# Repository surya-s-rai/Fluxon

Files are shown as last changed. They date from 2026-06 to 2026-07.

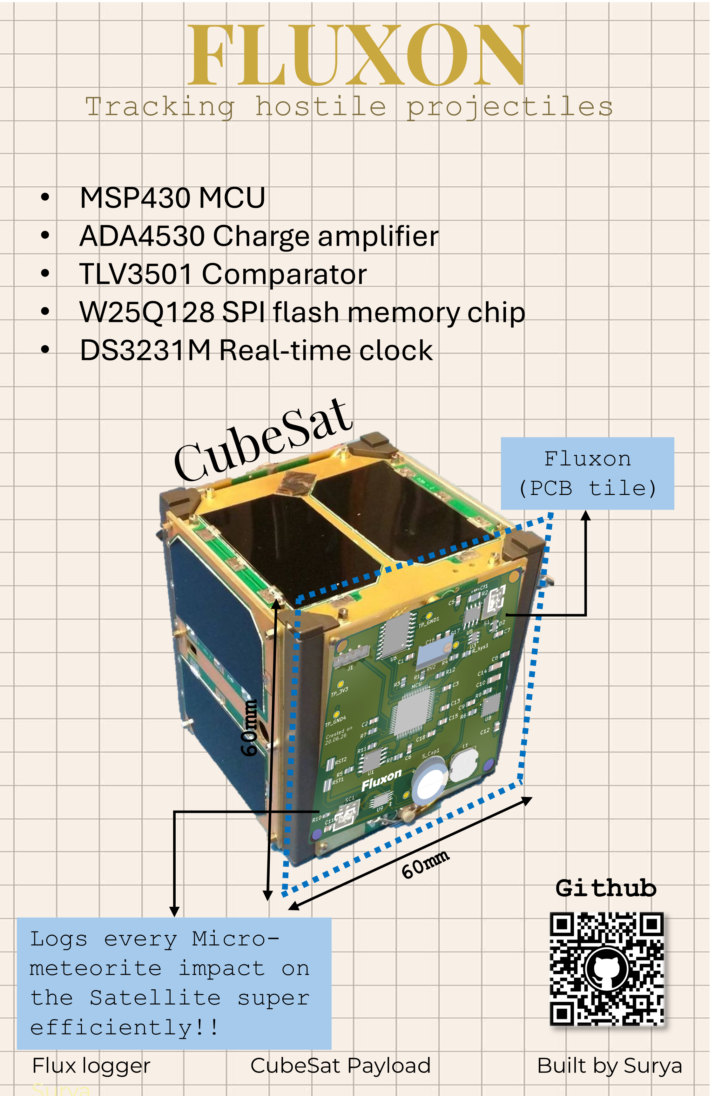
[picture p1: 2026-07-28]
Docs/fallout_Zine.png

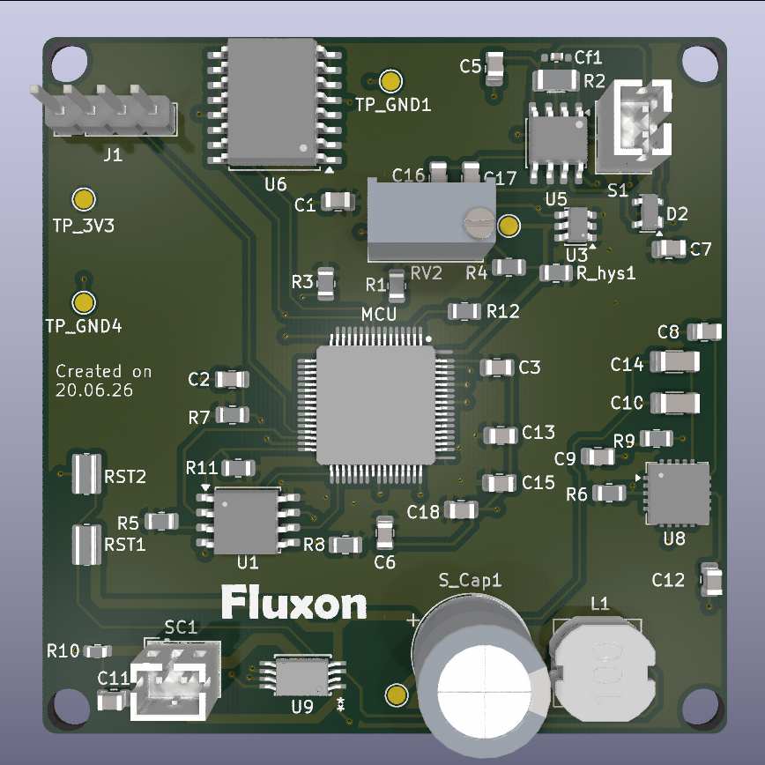
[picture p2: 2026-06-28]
Photos/Front 3d view.png

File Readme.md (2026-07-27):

# Important Information
## Why I did not made a CAD model for my project
Since it is an Iot device designed to be mounted on the CubeSat specifically on it's sidewall, therefore Satellite's outer body made up of Aluminium alloys protects Fluxon from the harsh environment outside. Zine page illustrating Fluxon outside the body is just for the visual representation.

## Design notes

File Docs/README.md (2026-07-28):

# Fluxon
## Project Overview
<p align="center">

fallout_Zine

</p>
<br><br>

__Fluxon__ - A PVDF Sensor based Flux logger that collects collision data, a especailly designed payload for CubeSat\
Collects useful data values once embedded on side walls of the satellite as shown in the Zine page above.
<br><br>


 ## Why I made this
 I made this project for a hardware hackathon called fallout organised by [Hack Club](https://github.com/hackclub), and particularly choosed to make this Iot device as i wanted to make a prototype of something real used in spacecrafts.
 ## Why it is relevant
 * Scientific value: Current flux models like [ORDEM](https://orbitaldebris.jsc.nasa.gov/modeling/ordem.html) and [MASTER](https://conference.sdo.esoc.esa.int/proceedings/sdc3/paper/92/SDC3-paper92.pdf) rely mainly on simulations and ground based radar data. A physical sensor mounted on small satellite misson measures impact data better than any simulation can replicate.
 * Cost effective: Commercial impact detectors used in experiments cost thousands of dollars, whereas Fluxon is an open source, low cost substitute PCB board.
 * Mechanical compatibility with real CubeSats: The 60mm x 60mm form factor matches the standard face panel dimensions of CubeSat.
 * Solar powered: The SPV1040 maximum power point tracker(MPPT) harvests energy form solar cell and charges the supercapacitor which reduces the burden of holding a separate battery into a small scale satellite.
 * Mass-frequency distribution: This statistically relevant distribution is obtained from the measured peak voltage which is proportional to mechanical impulse delivered on the aluminium face panel.
 * Flux density: The DS3231 which is a highly accurate real time clock(RTC) helps us to measure particle flux in units of particles per area per second. Flux density is meaningful beacause it varies with orbital altitude, inclination and the time of year(the earth's debris envionment is not uniform).
 * Impact direction: If we embed Fluxon on each face panel of CubeSat, we can calculate angular distribution of impact using parameters like time difference between sensor pairs, speed of sound in aluminium (6320 m/s) and known sensor geometry.
 ## How it works
 The payload is mainly divided into 4 major chunks-
 ### 1. Sensor Frontend (Impact Detection Hardware)
Converts tiny charge generted by the peizoelectric sensors into a measurable voltage.



 ### 2. Signal Conditioning
 Gives Amplified, noise reduced input for Microcontroller unit. 
 
 

 ### 3. Microcontroller and Firmware
 Processes sensor data and uses specific codes that brigdes the hardware requirements.
 


 ### 4. Data Storage System
 Uses W25Q128JV to store collected events.
 


 ## What's inside this folder
 # PCB Files:
 `* flux logger project.kicad_sch`-contains an illustrative layout of parts and wires used in the project
 
 

 `* flux logger project.kicad_pcb`\-The actual pcb layout with all components placed and routed
 


 # Firmware:
 `* Firmware` folder contains hardware specific C codes for parts to operate
 
 # Other files
 `* Flux logger project.kicad_pro`-links `kicad_sch` and `kicad_pcb` files.
 
 `ChargeAmplifier.kicad_sch`,`TPS_Vin.kicad_sch` and`Thre_comp.Kicad_sch` are sub parts of main schema file i.e. `flux logger project.Kicad_sch` 
 ## Build Guide
 1. Replicate the Repository into your local environment
 
 2. View `flux logger project.kicad_sch`,`flux logger project.kicad_pcb` along with the pcb's 3D View on [Kicad](https://www.kicad.org/)
 
 3. PCB Assembly\
 Solder components in the following order:
 resistors and capacitors,Sensor, ADA4530-1, MSP430, W25Q128JV, Connectors and testpoints

 4. Check High Impedance Areas
 Ensure gaurd ring surrounding Amplifier and Sensor input traces.
 Also, keep sensor input clean and isolated.

 5. Power Supply Check
 Apply 3.3V Supply according to `.kicad_sch` file and verify 3.3V rail across each IC.

 6. Firmware Installation

 #### Required Software
 * Visual Studio Code Editor
 * PlatformIO Extension
 * Texas Instruments MSP430 Toolchain

 7. Build and Upload Firware

 * Open Firmware folder and run `pio run` on CLI

 * Use upload Button on PlatformIO in order to upload the programme

## BOM
| Value | Reference | Footprint | Qty | Unit Price | Total Price | URL |
| :--- | :--- | :--- | :--- | :--- | :--- | :--- |
| 100nf | C1,C2,C3,C5,C6,C7,C13,C15,C16 | Capacitor_SMD:C_0805_2012Metric | 9 | $0.01 | $0.11 | https://projectpoint.in/index.php?route=product/product&product_id=636107122 |
| 1uf | C17,C12 | Capacitor_SMD:C_0805_2012Metric | 2 | $0.02 | $0.05 | https://robu.in/product/1uf-1000nf-50v-capacitor-0805-smd-package-pack-of-10/ |
| 10uF | C9,C11,C8,C18 | Capacitor_SMD:C_0805_2012Metric | 4 | $0.04 | $0.16 | https://robu.in/product/grm21bb31c106me15l-murata-electronics-16v-10uf-%C2%B120-0805-multilayer-ceramic-capacitors-mlcc-smd-smt-rohs/ |
| 22uF | C10,C14 | Capacitor_SMD:C_1206_3216Metric | 2 | $0.01 | $0.02 | https://robu.in/product/cs3216x5r226m6r3nri-samwha-6-3v-22uf-x5r-%C2%B120-1206-multilayer-ceramic-capacitors-mlcc-smd-smt-rohs/ |
| 10pf | Cf1 | Resistor_SMD:R_0603_1608Metric | 1 | $0.01 | $0.01 | https://robu.in/product/10pf-0603-surface-mount-multilayer-ceramic-capacitor-pack-of-50/ |
| 100mf | S_Cap1 | Capacitor_THT:CP_Radial_D10.0mm_P5.00mm | 1 | $1.18 | $1.18 | https://robu.in/product/0-1f-5-5v-dip-super-capacitor/ |
| Conn_01x04 | J1 | Connector_PinHeader_2.54mm:PinHeader_1x02_P2.54mm_Vertical | 2 | $0.02 | $0.04 | https://ifuturetech.org/product/xh2-54-2p-curved-needle-connector-holder-2-54mm-white/ |
| 22uH | L2 | Inductor_SMD:L_7.3x7.3_H4.5 | 1 | $0.10 | $0.10 | https://robu.in/product/68mm-22%C2%B5h-dip-power-inductor-pack-of-5/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 |
| 10K | RV2 | Potentiometer_THT:Potentiometer_Bourns_3296W_Vertical | 1 | $0.17 | $0.17 | https://projectpoint.in/index.php?route=product/product&product_id=1500453261 |
| 4.7K | R1,R3 | Resistor_SMD:R_0805_2012Metric | 2 | $0.01 | $0.01 | https://robu.in/product/yageo-4-7k-ohm-1-4w-0805-surface-mount-resistor-pack-of-50/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 |
| 100M | R2 | Resistor_SMD:R_1206_3216Metric | 1 | $1.01 | $1.01 | https://srkelectronics.in/product/1-mega-ohm-1206-smd-resistor-cfr-pack-of-100/ |
| 470K | R10 | Resistor_SMD:R_0603_1608Metric | 1 | $0.10 | $0.10 | https://quartzcomponents.com/products/470k-ohm-0603-package-1-10w-smd-resistor-5-tolerance-pack-of-20-pieces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 |
| 10K | R5,R8,R4,R11 | Resistor_SMD:R_1206_3216Metric | 4 | $0.01 | $0.03 | https://robu.in/product/10k-ohm-1-4w-1206-surface-mount-chip-resistor-pack-of-100/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 |
| 13.3K | R6 | Resistor_SMD:R_1206_3216Metric | 1 | $0.02 | $0.02 | https://projectpoint.in/index.php?route=product/product&product_id=499506064082 |
| 47k | R7 | Resistor_SMD:R_1206_3216Metric | 1 | $0.02 | $0.02 | https://projectpoint.in/index.php?route=product/product&product_id=501263610758 |
| 9.1K | R9 | Resistor_SMD:R_1206_3216Metric | 1 | $0.02 | $0.02 | https://projectpoint.in/index.php?route=product/product&product_id=502522332251 |
| 220K | RST1 | Resistor_SMD:R_1206_3216Metric | 1 | $0.02 | $0.02 | https://projectpoint.in/index.php?route=product/product&product_id=501903421507 |
| 100K | RST2 | Resistor_SMD:R_1206_3216Metric | 1 | $0.01 | $0.01 | https://robu.in/product/100k-ohm-1-4w-1206-surface-mount-chip-resistor-pack-of-100/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 |
| 1M | R_hys1 | Resistor_SMD:R_0603_1608Metric | 1 | $0.11 | $0.11 | https://quartzcomponents.com/products/yageo-1m-ohm-0603-package-1-10w-smd-resistor-1-tolerance-pack-of-20-pieces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 |
| 1K | R12 | Resistor_SMD:R_1206_3216Metric | 1 | $0.01 | $0.01 | https://robu.in/product/1k-ohm-1-4w-1206-surface-mount-chip-resistor-pack-of-100/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 |
| PDVF Sensor | S1 | Connector_JST:JST_PH_B2B-PH-K_1x02_P2.00mm_Vertical | 1 | $0.50 | $0.50 | https://www.flyrobo.in/10cm-2pin-jst-male-female-plug-connector-plug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 |
| Solar_Cell | SC2 | Connector_JST:JST_PH_B2B-PH-K_1x02_P2.00mm_Vertical | 1 | $0.50 | $0.50 | https://www.flyrobo.in/10cm-2pin-jst-male-female-plug-connector-plug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 |
| PRTR5V0U2X | D2 | Package_TO_SOT_SMD:SOT-143 | 1 | $1.00 | $1.00 | https://www.digikey.in/en/products/detail/microchip-technology/MIC5203-5.0YM4-TR/771725 |
| W25Q128JVS | U1 | Package_SO:SOIC-8_5.3x5.3mm_P1.27mm | 1 | $2.65 | $2.65 | https://evelta.com/serial-nor-flash-memory-128mbit-8pin-soic/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 |
| TLV3501AIDBV | U3 | Package_TO_SOT_SMD:SOT-23-6 | 1 | $4.00 | $4.00 | https://www.mouser.in/ProductDetail/Texas-Instruments/TLV3501AIDR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 |
| MSP430FR5994IPMR.B | U4 | MCU:MSP430FR footprint | 1 | $11.06 | $11.06 | https://www.mouser.in/ProductDetail/Texas-Instruments/MSP430FR5994IPMR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 |
| ADA4530-1 | U5 | Package_SO:SOIC-8_3.9x4.9mm_P1.27mm | 1 | $42.61 | $42.61 | https://www.mouser.in/ProductDetail/Analog-Devices/ADA4530-1ARZ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 |
| DS3231M | U6 | Package_SO:SOIC-16W_7.5x10.3mm_P1.27mm | 1 | $2.60 | $2.60 | https://robu.in/product/ds3231-ic-real-time-clock-integrated-rtc-tcxo-crystal/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 |
| TPS7A4701xRGW | U8 | Package_DFN_QFN:Texas_RGW0020A_VQFN-20-1EP_5x5mm_P0.65mm_EP3.15x3.15mm_ThermalVias | 1 | $6.44 | $6.44 | https://www.lioncircuits.com/parts/TPS7A4701RGWR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 |
| SPV1040TTR | U9 | Package_DFN_QFN:SOIC_1040T_STM | 1 | $4.07 | $4.07 | https://www.digikey.in/en/products/detail/stmicroelectronics/SPV1040TTR/2672694 |
| TesPoint | TP_3v3, TP_GND1,TP_GND4, TP_SCAP1,TP_COMP1 | TestPoint:TestPoint_Pad_D1.5mm | 5 | $0.19 | $0.93 | https://in.element14.com/keystone/5000/test-point-pcb-color-coded/dp/2250281 |
|  |  |  |  | TOTAL= | $79.56 |  |

  ## Credit
  I thank this project to-\
  [Kicad](https://www.kicad.org/)\
  [HackClub Fallout](https://fallout.hackclub.com)\
  my beloved parents and friends...

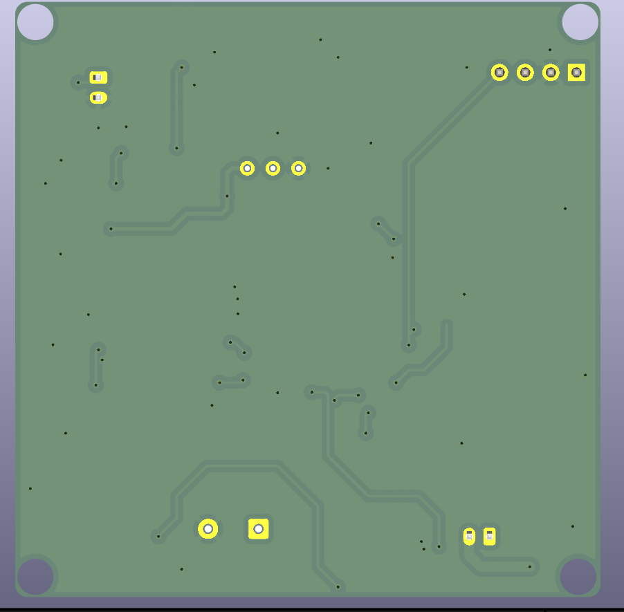
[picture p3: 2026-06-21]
Photos/3D View Back.png

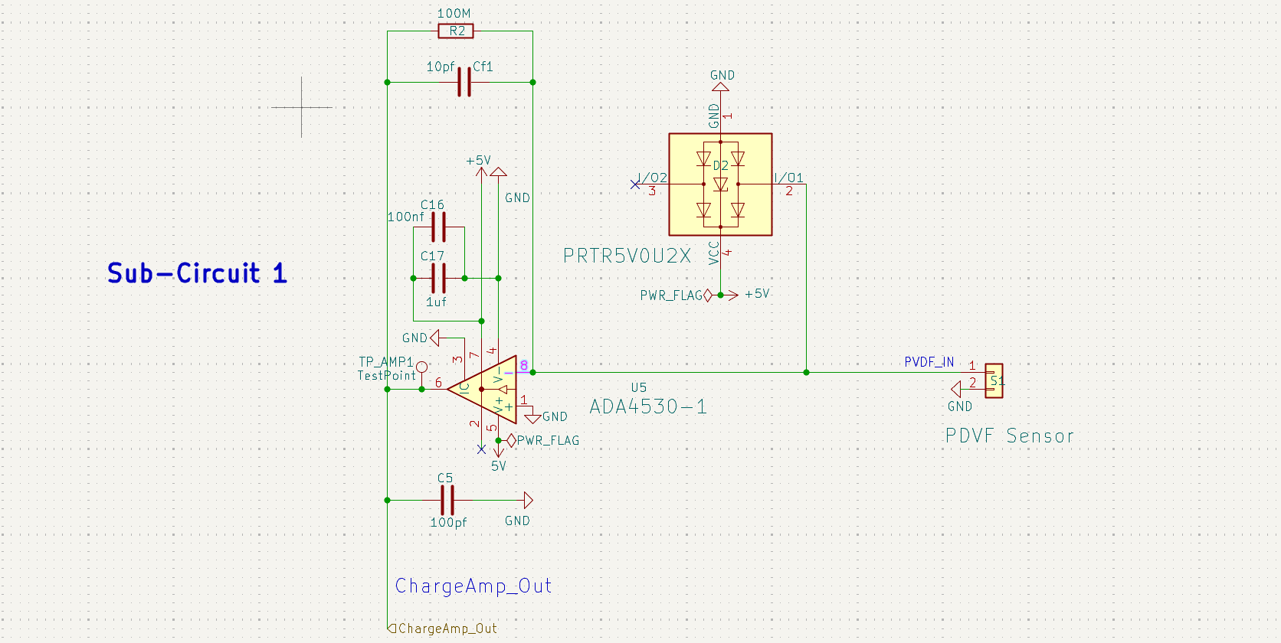
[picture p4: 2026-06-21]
Photos/Sensor and Amp Schema.png

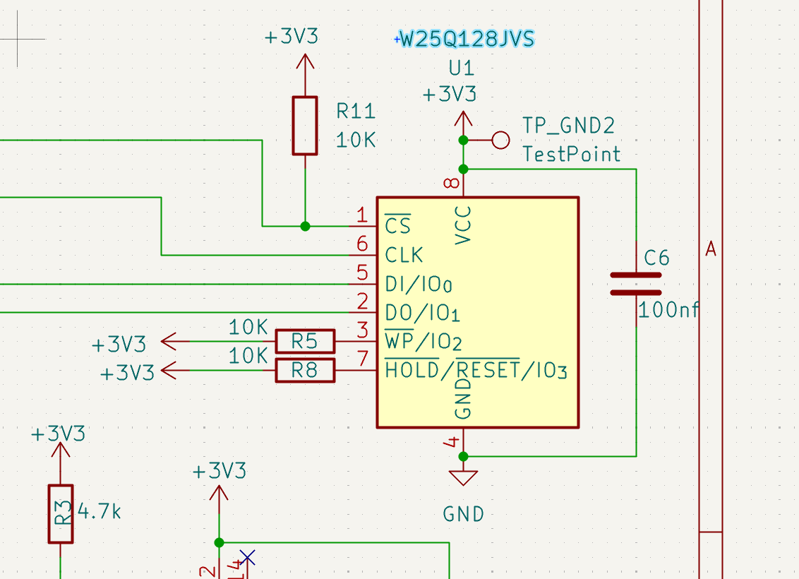
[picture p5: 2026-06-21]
Photos/RTC Schema.png

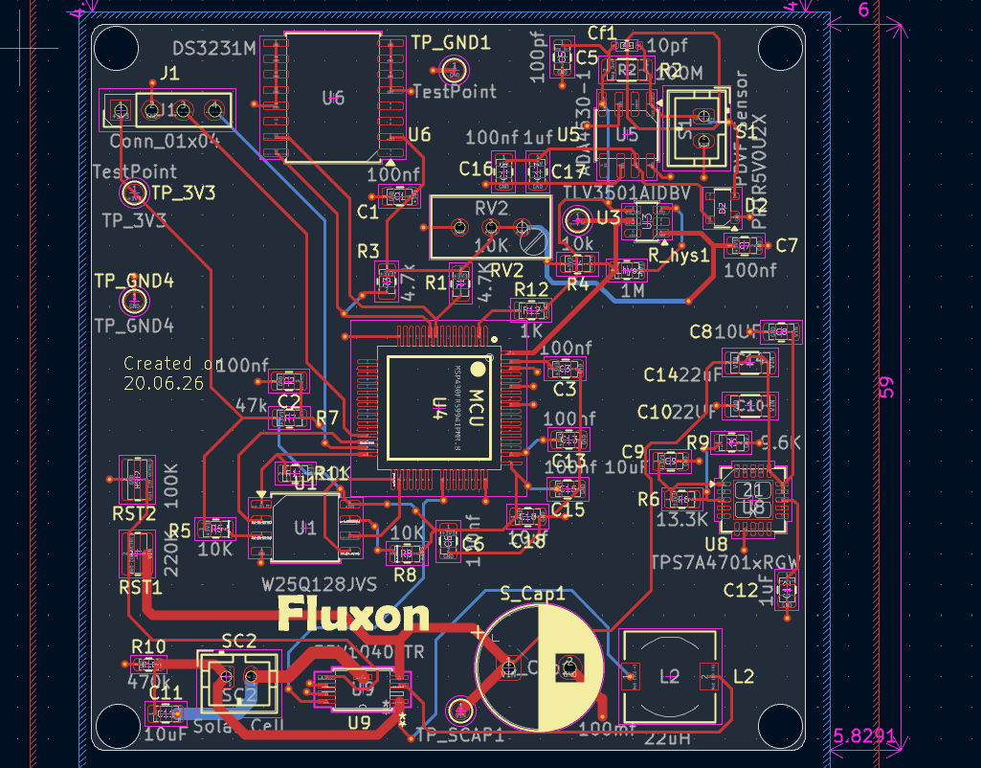
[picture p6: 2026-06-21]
Photos/PCB editor Front view.png

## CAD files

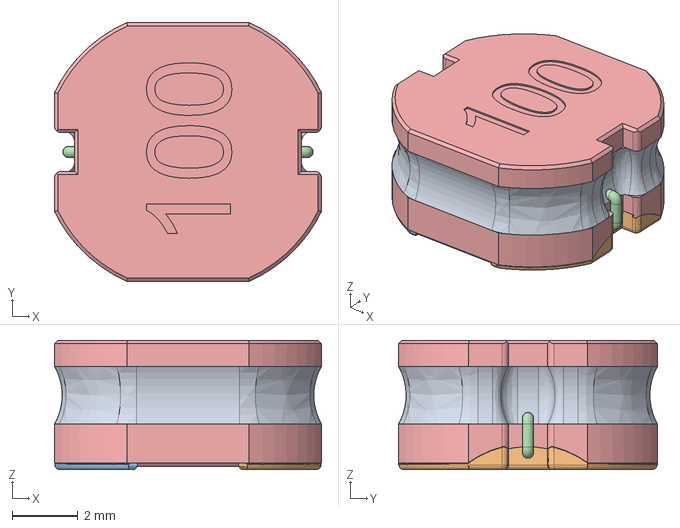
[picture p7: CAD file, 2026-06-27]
3rd party Assets/Inductor 3d model only/SRN8040-220M.stp
8.15 x 7.90 x 3.95 mm

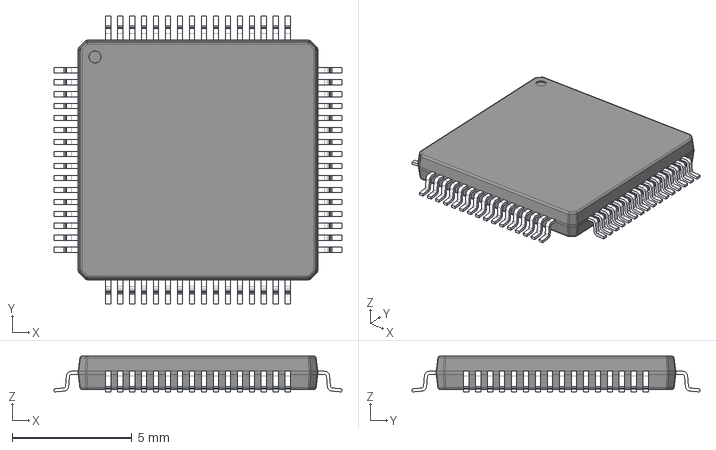
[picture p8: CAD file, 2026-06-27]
3rd party Assets/MCU/MCU 3d model/MSP430FR5994IPMR.stp
12.0 x 12.0 x 1.50 mm
BODY-QFP
LEAD-QFP x 64

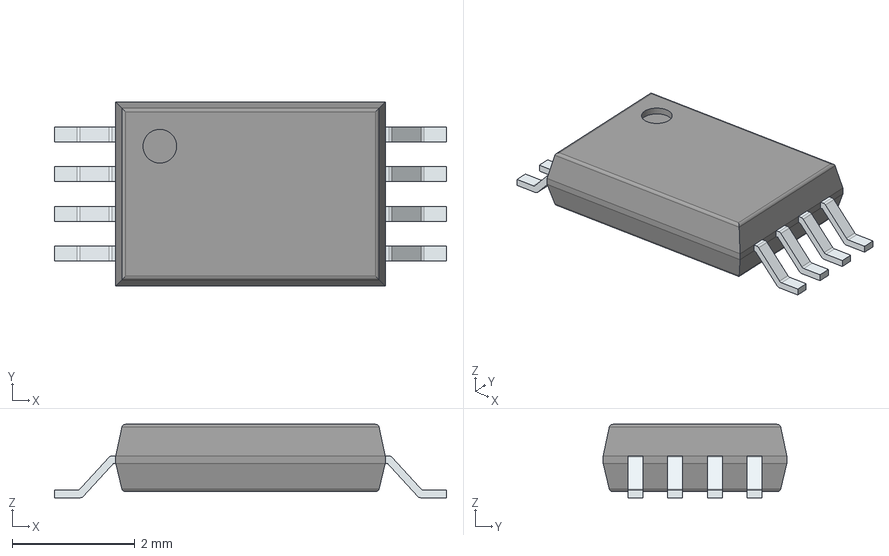
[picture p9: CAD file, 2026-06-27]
3rd party Assets/SPV1040TTR/SPV1040TTR 3d model/SPV1040TTR.stp
6.40 x 3.00 x 1.20 mm
PinsArrayLR

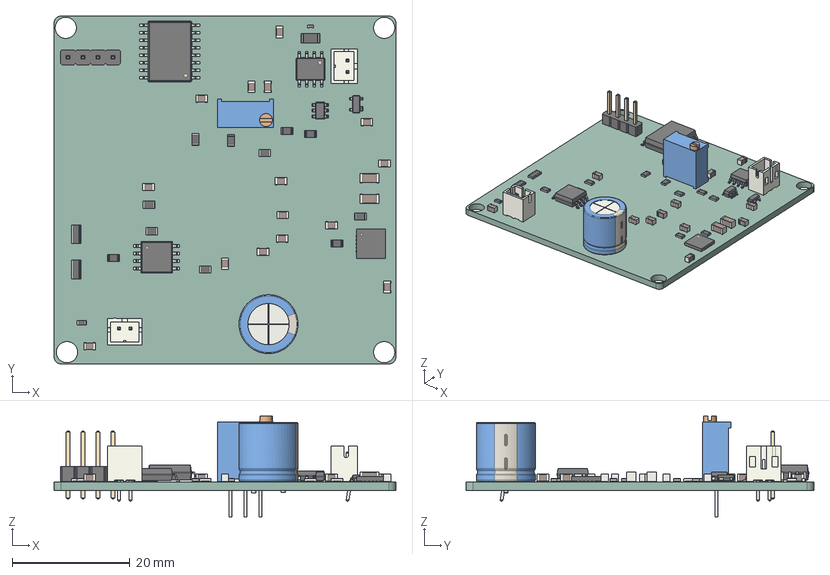
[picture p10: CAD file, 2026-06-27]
CAD/flux logger project.step
58.0 x 59.0 x 17.1 mm
JST_B2B_PH_K x 2
CP_Radial_D100mm_P500mm
C_0805_2012Metric x 15
SOIC-8_3.9x4.9mm_P1.27mm
R_0805_2012Metric x 11
R_0612_1632Metric x 2
C_1206_3216Metric x 2
Potentiometer_Bourns_3296W_Vertical
SOT-23-6
PinHeader_1x04_P254mm_Vertical
C_0402_1005Metric
SOIC-16W_7.5x10.3mm_P1.27mm
R_1206_3216Metric
SOIC-8_5.3x5.3mm_P1.27mm
R_0603_1608Metric
SOT-143
Texas_RGW0020A_VQFN-20-1EP_5x5mm_P0.65mm_EP3.15x3.15mm
flux logger project_PCB

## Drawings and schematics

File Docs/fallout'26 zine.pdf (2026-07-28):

# FLUXON 60mm

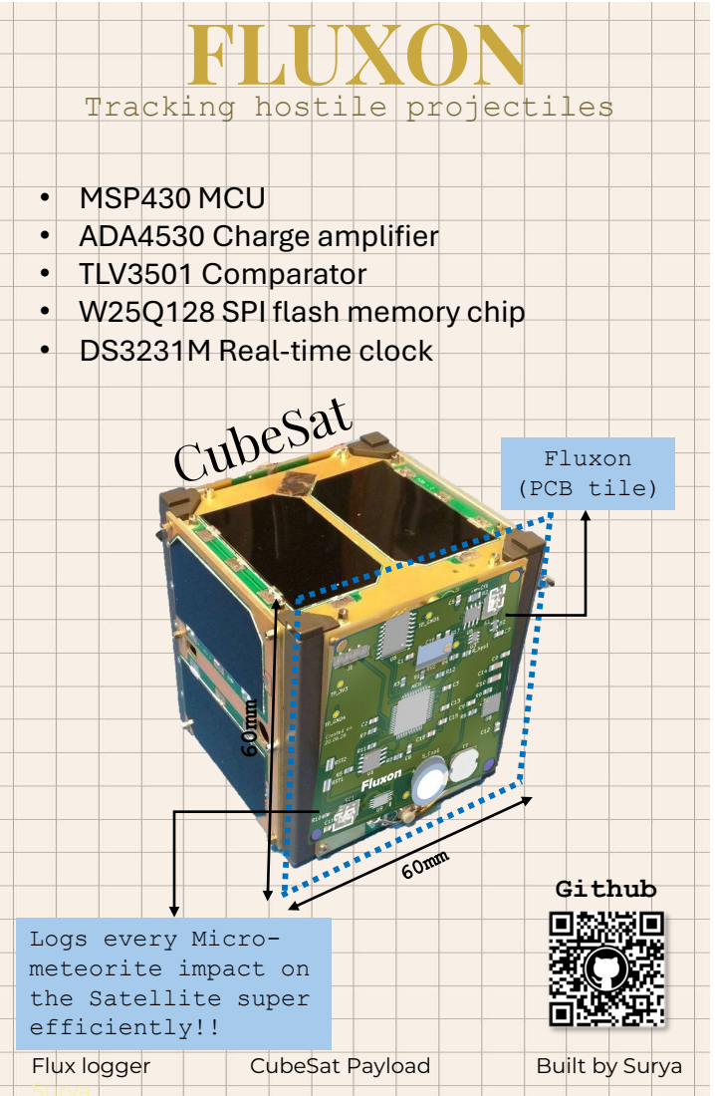
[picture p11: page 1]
Github; Flux logger; CubeSat Payload; Built by Surya; Fluxon; (PCB tile)

Tracking hostile projectiles

• MSP430 MCU
• ADA4530 Charge amplifier
• TLV3501 Comparator
• W25Q128 SPI flash memory chip
• DS3231M Real-time clock

Logs every Micro-
meteorite impact on
the Satellite super
efficiently!!
Surya

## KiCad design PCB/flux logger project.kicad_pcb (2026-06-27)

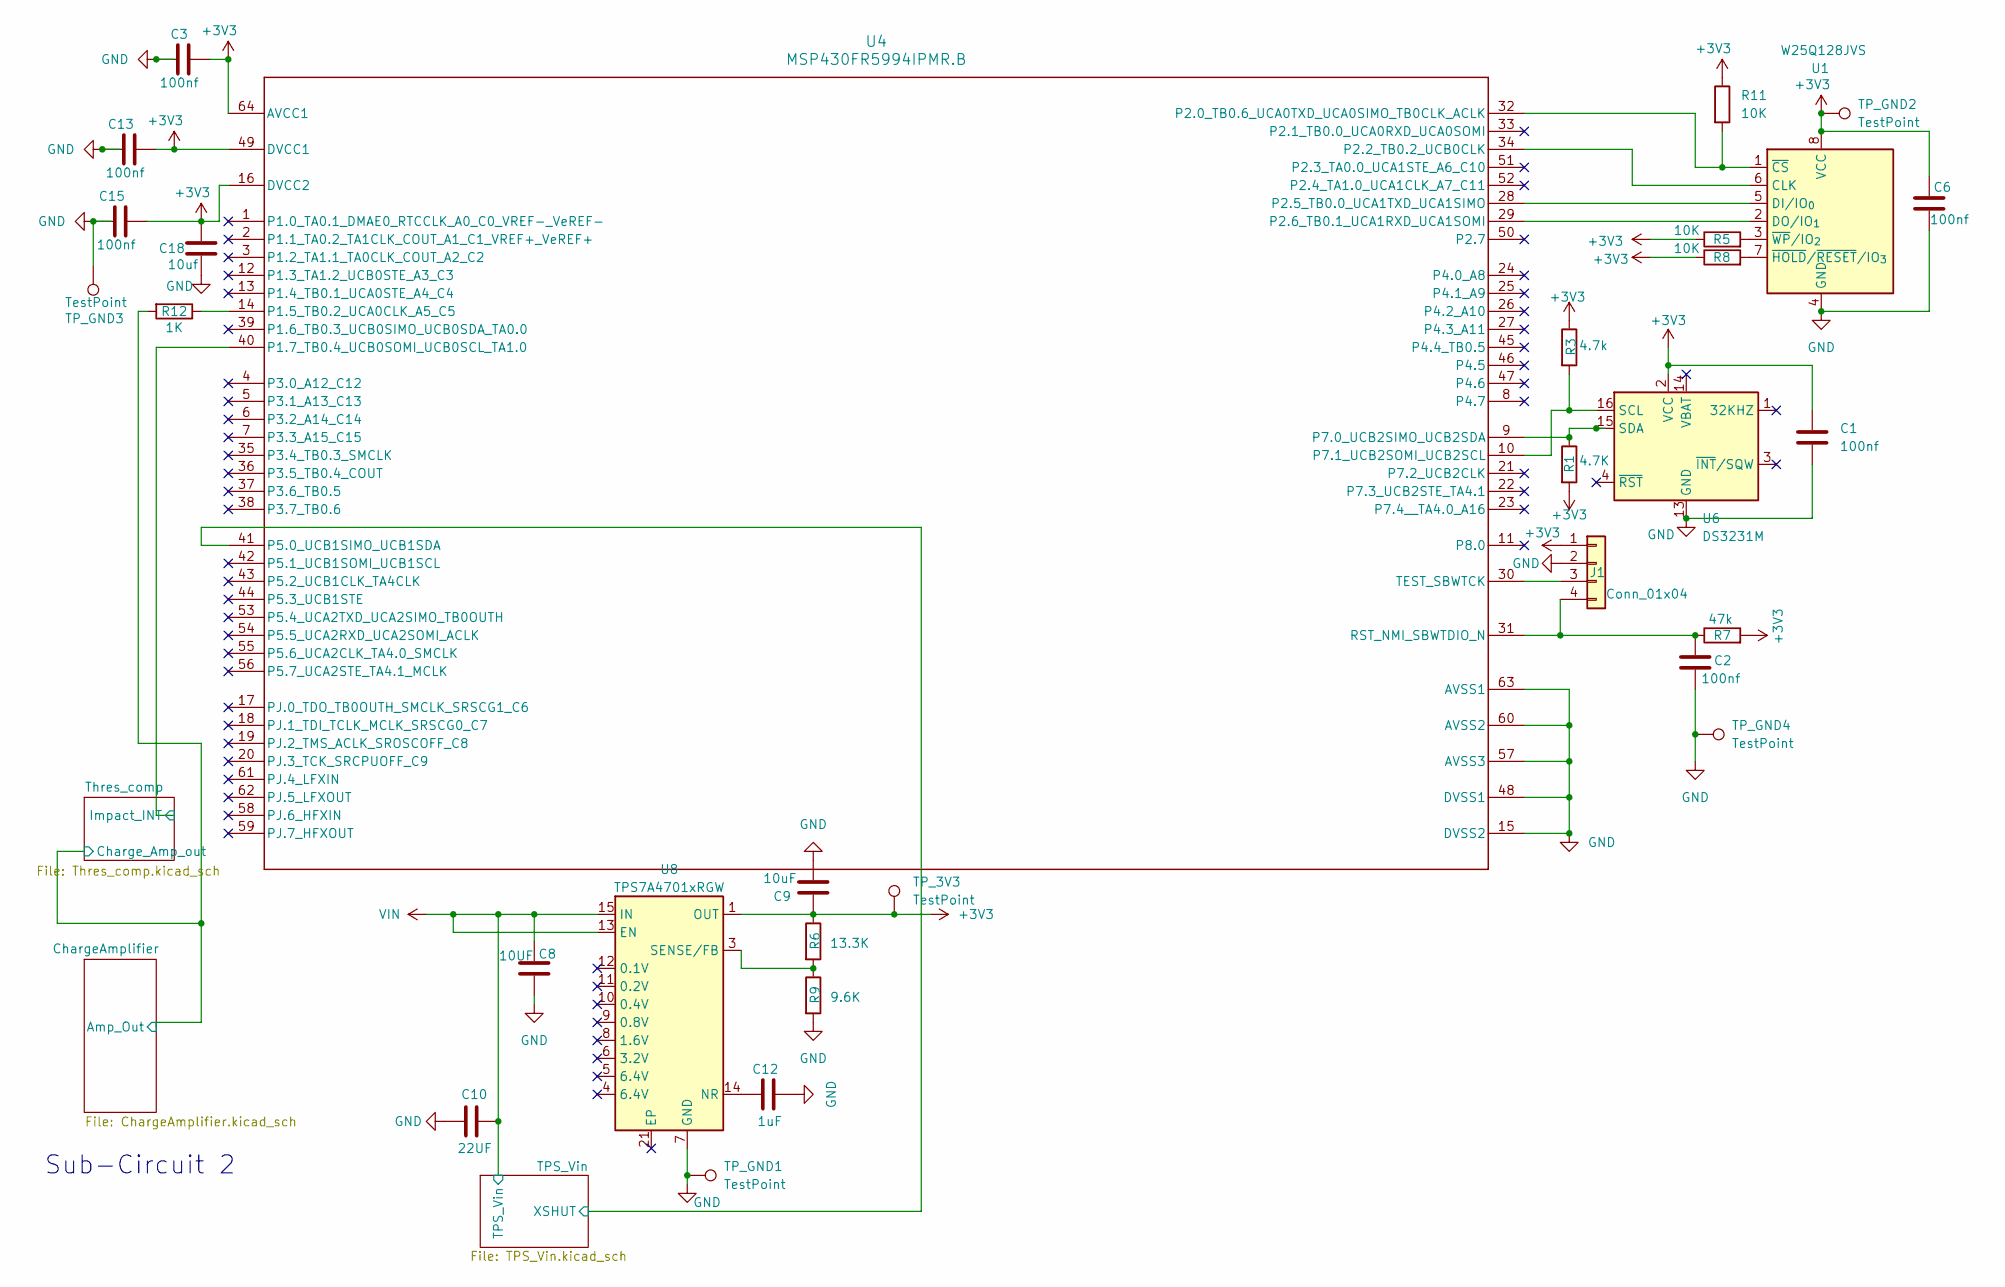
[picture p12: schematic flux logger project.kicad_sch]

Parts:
C1, C2, C3, C6, C13, C15: 100nf; C_0805_2012Metric
C8: 10UF; C_0805_2012Metric
C9: 10uF; C_0805_2012Metric
C10: 22UF; C_1206_3216Metric
C12: 1uF; C_0805_2012Metric
C18: 10uf; C_0805_2012Metric
J1: Conn_01x04; PinHeader_1x04_P2.54mm_Vertical
R1: 4.7K; R_0805_2012Metric
R3: 4.7k; R_0805_2012Metric
R5, R8, R11: 10K; R_0805_2012Metric
R6: 13.3K; R_0805_2012Metric
R7: 47k; R_0805_2012Metric
R9: 9.6K; R_0805_2012Metric
R12: 1K; R_0805_2012Metric
TP_3V3: TestPoint; TestPoint_Pad_D1.5mm
TP_GND1, TP_GND2, TP_GND3, TP_GND4: TestPoint; TestPoint_Pad_D1.5mm
U1: W25Q128JVS; SOIC-8_5.3x5.3mm_P1.27mm
U4: MSP430FR5994IPMR.B; MSP430FR footprint
U6: DS3231M; SOIC-16W_7.5x10.3mm_P1.27mm
U8: TPS7A4701xRGW; Texas_RGW0020A_VQFN-20-1EP_5x5mm_P0.65mm_EP3.15x3.15mm_Ther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

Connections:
+3V3: C1.1, C3.2, C6.1, C9.1, C13.2, C15.2, C18.1, J1.1, R1.2, R3.1, R5.1, R6.1, R7.2, R8.1, R11.1, TP_3V3.1 (1_1), TP_GND2.1, U1.8 (VCC), U4.16 (DVCC2), U4.49 (DVCC1), U4.64 (AVCC1), U6.2 (VCC), U8.1 (OUT); also elsewhere on the board
/ChargeAmplifier/Amp_Out: R12.2; also elsewhere on the board
/TPS_Vin/XSHUT: U4.41 (P5.0_UCB1SIMO_UCB1SDA); also elsewhere on the board
/Thres_comp/Impact_INT: U4.40 (P1.7_TB0.4_UCB0SOMI_UCB0SCL_TA1.0); also elsewhere on the board
GND: C1.2, C2.2, C3.1, C6.2, C8.2, C9.2, C10.2, C12.2, C13.1, C15.1, C18.2, J1.2, R9.2, TP_GND1.1 (1_1), TP_GND3.1, TP_GND4.1 (1_1), U1.4 (GND), U4.15 (DVSS2), U4.48 (DVSS1), U4.57 (AVSS3), U4.60 (AVSS2), U4.63 (AVSS1), U6.5 (GND), U6.6 (GND), U6.7 (GND), U6.8 (GND), U6.9 (GND), U6.10 (GND), U6.11 (GND), U6.12 (GND), U6.13 (GND), U8.7 (GND); also elsewhere on the board
unnamed: J1.3, U4.30 (TEST_SBWTCK)
unnamed: C2.1, J1.4, R7.1, U4.31 (RST_NMI_SBWTDIO_N)
unnamed: U1.6 (CLK), U4.34 (P2.2_TB0.2_UCB0CLK)
unnamed: U1.5 (DI/IO_{0}), U4.28 (P2.5_TB0.0_UCA1TXD_UCA1SIMO)
unnamed: U1.2 (DO/IO_{1}), U4.29 (P2.6_TB0.1_UCA1RXD_UCA1SOMI)
unnamed: R11.2, U1.1 (~CS), U4.32 (P2.0_TB0.6_UCA0TXD_UCA0SIMO_TB0CLK_ACLK)
unnamed: R8.2, U1.7 (~HOLD/~RESET/IO_{3})
unnamed: R5.2, U1.3 (~WP/IO_{2})
unnamed: R12.1, U4.14 (P1.5_TB0.2_UCA0CLK_A5_C5)
unnamed: R1.1, U4.9 (P7.0_UCB2SIMO_UCB2SDA), U6.15 (SDA)
unnamed: R3.2, U4.10 (P7.1_UCB2SOMI_UCB2SCL), U6.16 (SCL)
unnamed: C12.1, U8.14 (NR)
unnamed: R6.2, R9.1, U8.3 (SENSE/FB)
VIN: C8.1, C10.1, U8.13 (EN), U8.15 (IN), U8.16 (IN); also elsewhere on the board

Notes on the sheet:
Sub-Circuit 2

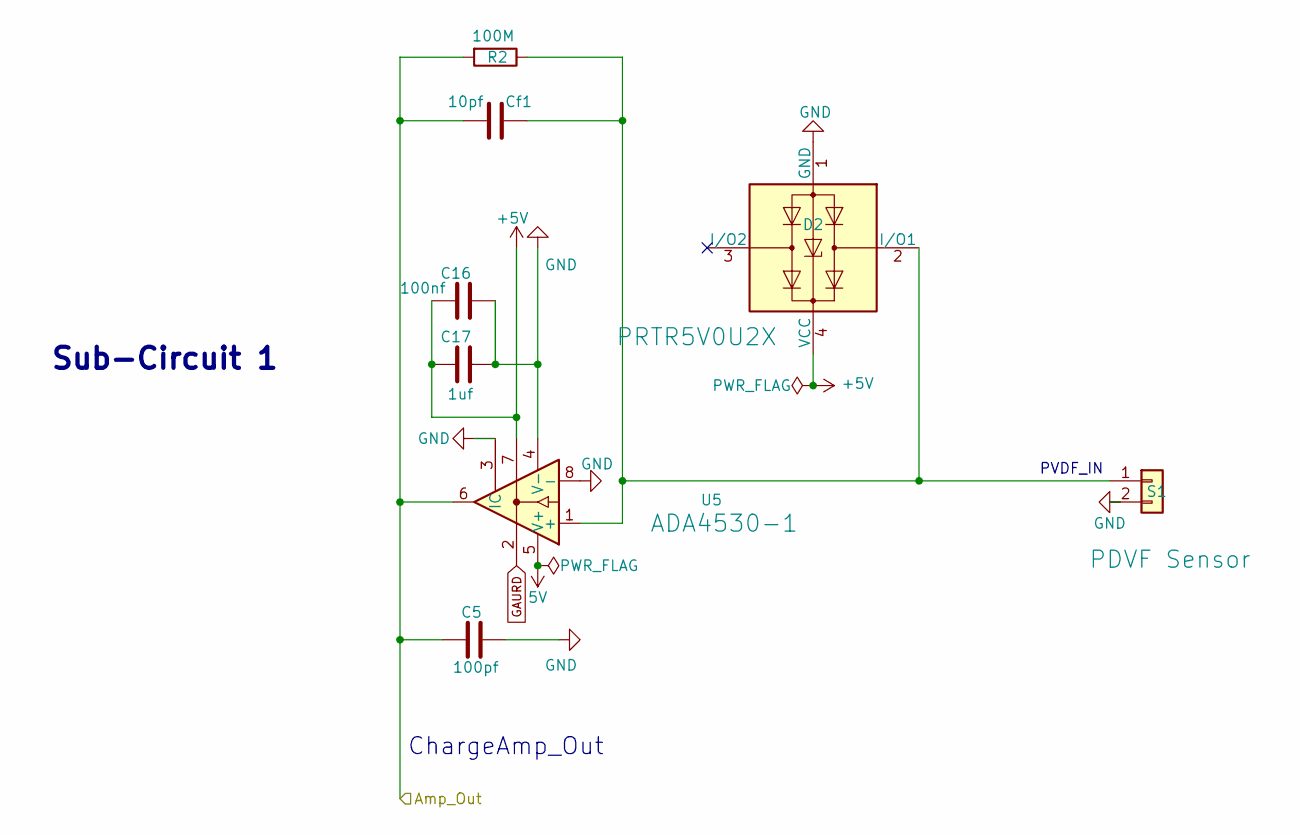
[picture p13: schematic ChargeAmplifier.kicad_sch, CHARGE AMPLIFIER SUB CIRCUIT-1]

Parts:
C5: 100pf; C_0805_2012Metric
C16: 100nf; C_0805_2012Metric
C17: 1uf; C_0805_2012Metric
Cf1: 10pf; C_0402_1005Metric
D2: PRTR5V0U2X; SOT-143
R2: 100M; R_1206_3216Metric
S1: PDVF Sensor; JST_PH_B2B-PH-K_1x02_P2.00mm_Vertical
U5: ADA4530-1; SOIC-8_3.9x4.9mm_P1.27mm

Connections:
5V: U5.5 (V+)
+5V: C16.1, C17.1, D2.4 (VCC), U5.7
/ChargeAmplifier/Amp_Out: C5.1, Cf1.2, R2.2, U5.6; also elsewhere on the board
GAURD: U5.2
GND: C5.2, C16.2, C17.2, D2.1 (GND), S1.2, U5.3 (IC), U5.4 (V-), U5.8 (-); also elsewhere on the board
unnamed: Cf1.1, D2.2 (I/O1), R2.1, S1.1, U5.1 (+)

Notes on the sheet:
ChargeAmp_Out
PVDF_IN
Sub-Circuit 1

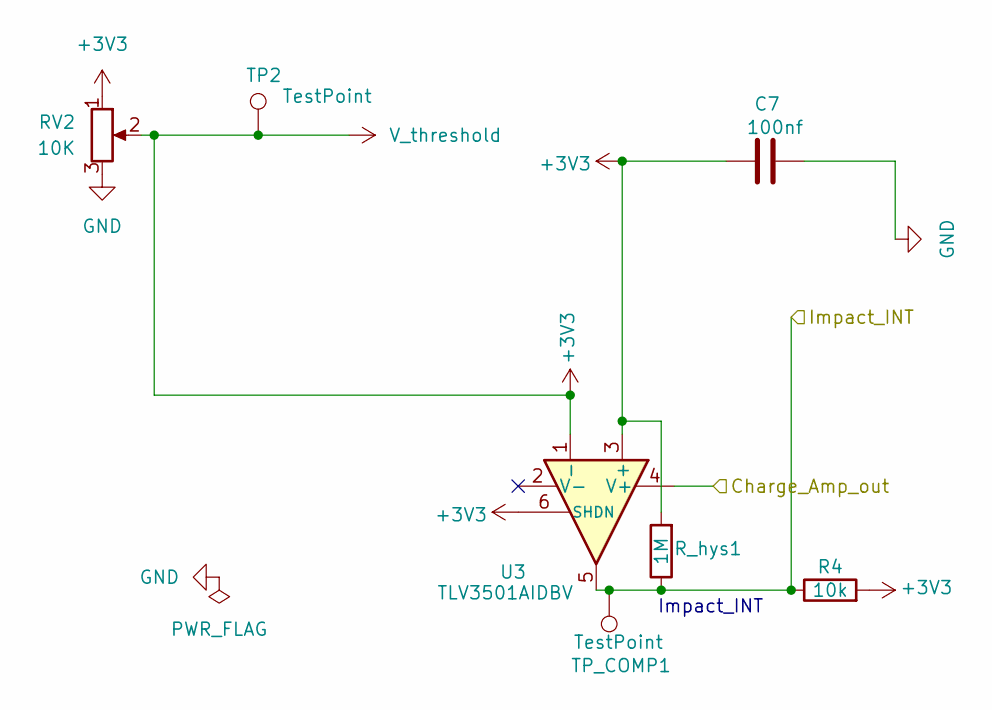
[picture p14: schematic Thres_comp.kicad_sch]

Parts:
C7: 100nf; C_0805_2012Metric
R4: 10k; R_0805_2012Metric
RV2: 10K; Potentiometer_Bourns_3296W_Vertical
R_hys1: 1M; R_0805_2012Metric
TP2: TestPoint; TestPoint_Pad_D1.5mm
TP_COMP1: TestPoint; TestPoint_Pad_D1.5mm
U3: TLV3501AIDBV; SOT-23-6

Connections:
+3V3: C7.1, R4.2, RV2.1, RV2.2, R_hys1.2, TP2.1, U3.1 (-), U3.3 (+), U3.6 (SHDN); also elsewhere on the board
/ChargeAmplifier/Amp_Out: U3.4 (V+); also elsewhere on the board
/Thres_comp/Impact_INT: R4.1, R_hys1.1, TP_COMP1.1 (1_1), U3.5; also elsewhere on the board
GND: C7.2, RV2.3; also elsewhere on the board

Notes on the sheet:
Impact_INT

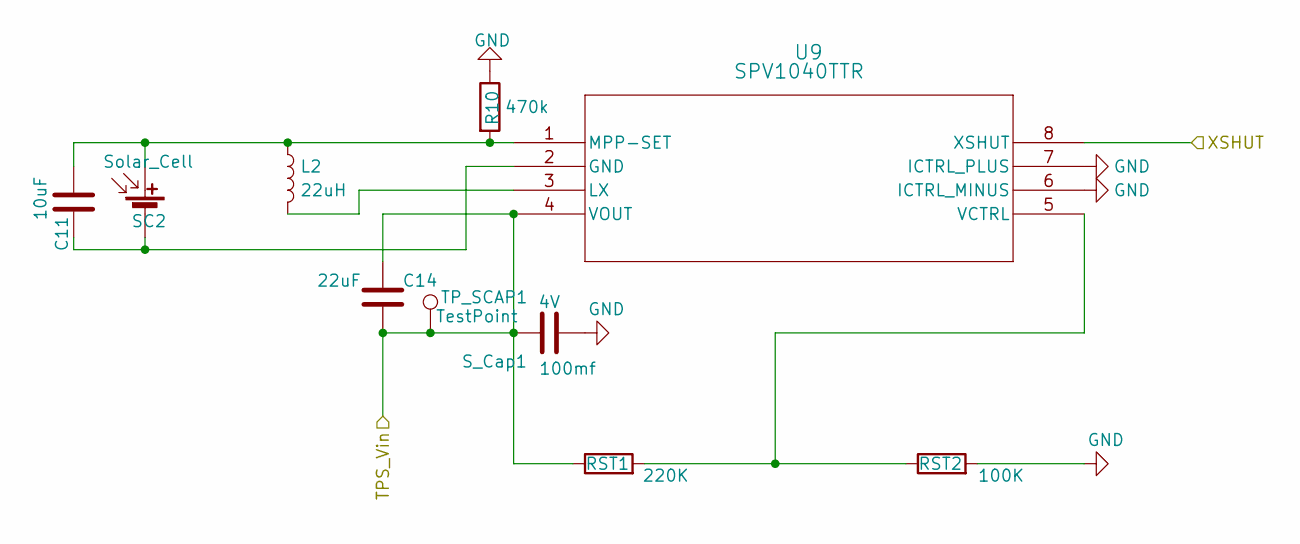
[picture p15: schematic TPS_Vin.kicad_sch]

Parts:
C11: 10uF; C_0805_2012Metric
C14: 22uF; C_1206_3216Metric
L2: 22uH; L_7.3x7.3_H4.5
R10: 470k; R_0603_1608Metric
RST1: 220K; R_0612_1632Metric
RST2: 100K; R_0612_1632Metric
SC2: Solar_Cell; JST_PH_B2B-PH-K_1x02_P2.00mm_Vertical
S_Cap1: 100mf; CP_Radial_D10.0mm_P5.00mm; Voltage 4V
TP_SCAP1: TestPoint; TestPoint_Pad_D1.5mm
U9: SPV1040TTR; SOIC_1040T_STM

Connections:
/TPS_Vin/XSHUT: U9.8 (XSHUT); also elsewhere on the board
GND: R10.1, RST2.2, S_Cap1.2, U9.6 (ICTRL_MINUS), U9.7 (ICTRL_PLUS); also elsewhere on the board
unnamed 11: C11.1, L2.1, R10.2, SC2.1 (+), U9.1 (MPP-SET); also elsewhere on the board
unnamed 12: C11.2, SC2.2 (-), U9.2 (GND); also elsewhere on the board
unnamed 24: L2.2, U9.3 (LX); also elsewhere on the board
unnamed: RST1.2, RST2.1, U9.5 (VCTRL)
VIN: C14.1, C14.2, RST1.1, S_Cap1.1, TP_SCAP1.1 (1_1), U9.4 (VOUT); also elsewhere on the board

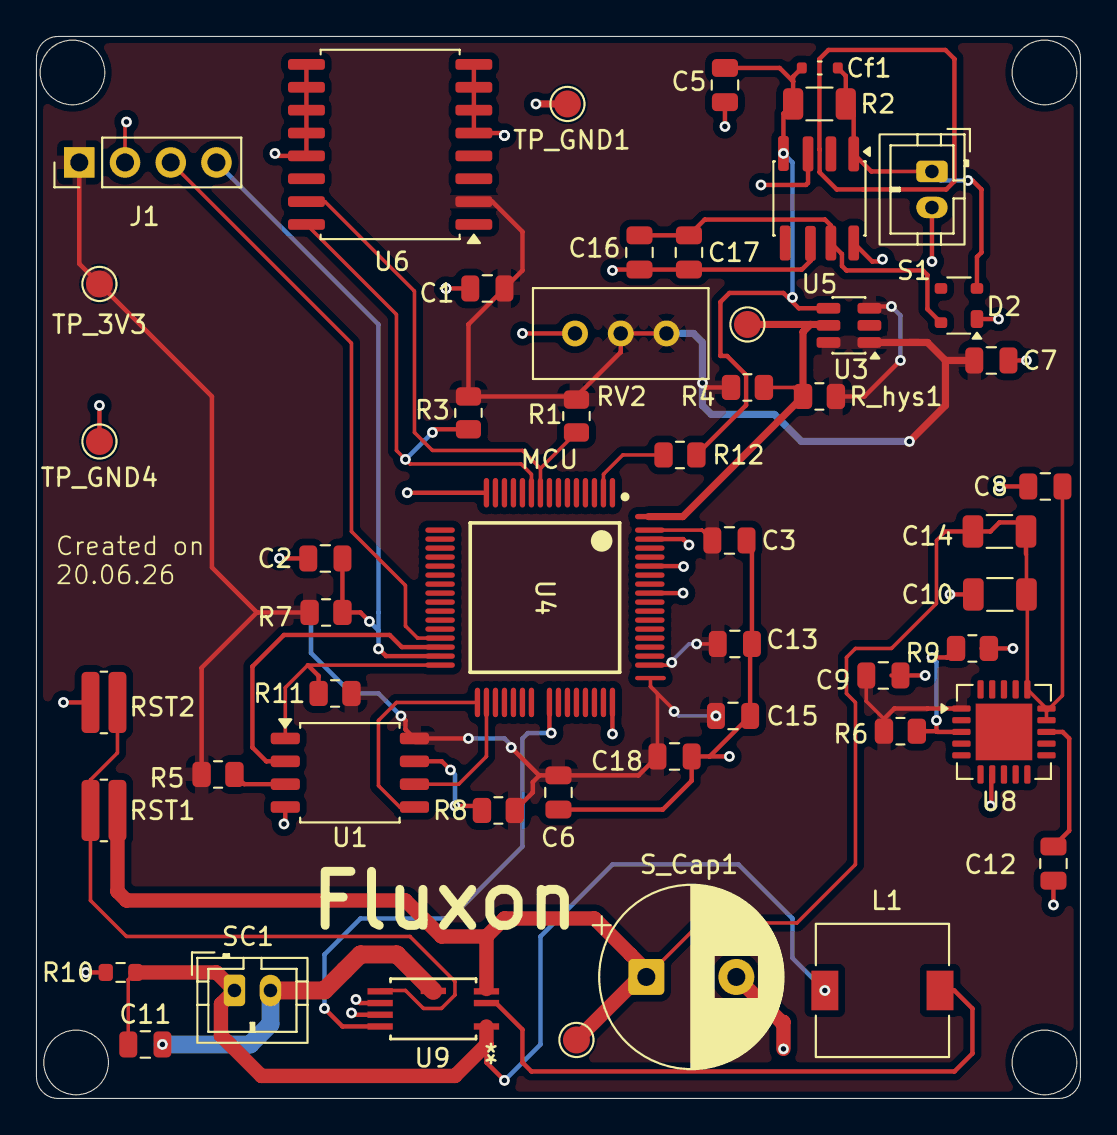
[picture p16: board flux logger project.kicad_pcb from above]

Board: 2 copper layers, 58.0 x 59.0 mm, 52 parts (0 on the bottom side), 25 nets.

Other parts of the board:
L1: 22uH; L_7.3x7.3_H4.5
SC1: Solar_Cell; JST_PH_B2B-PH-K_1x02_P2.00mm_Vertical

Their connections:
unnamed 11: L1.1, SC1.1 (+); also elsewhere on the board
unnamed 12: SC1.2 (-); also elsewhere on the board
unnamed 24: L1.2; also elsewhere on the board

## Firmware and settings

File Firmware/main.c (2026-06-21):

#include <msp430.h>
#include "impact_detector.h"
#include "adc_monitor.h"
#include "logger.h"
int main(void)
{
    WDTCTL = WDTPW | WDTHOLD;   // Stop watchdog timer
    Impact_Init();
    ADC_Init();
    Flash_Init();
    _enable_interrupt();
    while(1){
        if(impactFlag){
            impactFlag=0;
            Logger_SaveEvent();
        }
        __bis_SR_register(LPM3_bits + GIE);
    }
}

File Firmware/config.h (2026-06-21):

#ifndef CONFIG_H
#define CONFIG_H
#define IMPACT_PIN   BIT7
#define FLASH_CS_PIN  BIT0
#define DS3231_ADDR   0X68
#define ADC_SAMPLES   32
#define EVENT_SIGNATURE  0xAA
#endif

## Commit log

2026-06-21 added all imp files of this project
    [BOM updated1.xlsx, ChargeAmplifier.kicad_sch, TPS_Vin.kicad_sch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]
2026-06-21 Expand README with project details and functionality
    Added a section explaining how the Fluxon payload works, including details on the sensor frontend and signal conditioning.
2026-06-21 Update README with PCB files and BOM details
    Added PCB files and BOM information to the README.
2026-06-21 Enhance README with PCB and firmware details
    Updated README to include detailed PCB files, firmware instructions, and build guide.
2026-06-25 Add BOM section to README
    Added Bill of Materials (BOM) section with component details.
2026-06-26 Enhance README with project details and corrections
    Updated project description and added details about the Fluxon sensor's functionality and relevance. Improved formatting and corrected typos in the README.
2026-06-27 Create PCB
2026-06-27 Rename flux logger project.kicad_pcb to PCB/flux logger project.kicad_pcb
    [flux logger project.kicad_pcb]
2026-06-27 Rename flux logger project.kicad_pro to PCB/flux logger project.kicad_pro
2026-06-27 Rename flux logger project.kicad_sch to PCB/flux logger project.kicad_sch
    [flux logger project.kicad_sch]
2026-06-27 Create CAD
2026-06-27 Add README for CAD folder describing PCB model
2026-06-27 Enhance README with new image of pcb
    Updated README to include a new image and corrected typos.
2026-06-27 Fix unit prices in BOM section of README
    Updated unit prices for components in the BOM section.
2026-06-27 Rename BOM file in README
    Updated the bill of materials file name from 'BOM updated1.xlsx' to 'BOM(CSV).csv'.
2026-06-27 Clarify BOM file description in README
    Updated README to clarify BOM file description.
2026-06-27 Update README with new PCB layout image
    Added a new image to the README and updated the PCB layout description.
2026-06-27 Revise BOM with updated prices and links
    Updated BOM with new pricing and URLs for components.
2026-07-27 Add info.md with project CAD model explanation
    Added explanation for not creating a CAD model for the IoT device.
